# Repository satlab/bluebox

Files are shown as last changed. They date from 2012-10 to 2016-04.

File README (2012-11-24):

About the BlueBox
-----------------

The bluebox is a USB-powered ground station box design for the AAUSAT3 cubesat
satellite. The device firmware, control software and hardware is licensed under
the MIT license with the hope that it may be useful to other cubesat projects.

The device is built around the Analog Devices ADF7021 transceiver and controlled
by an Atmel ATMEGA32U4 microcontroller with hardware USB. The firmware makes use
of the open source LUFA USB stack and uses libusb and pyusb for communication
between the device and control program, bbctl.

How to install bbctl
--------------------

Go to software/bbctl and run:

    $ sudo python2 setup.py install

Note that you need gcc to compile the FEC extension module.

How to build and flash the firmware
-----------------------------------

In order to communicate with device without being root, copy 49-bluebox.rules
and 49-atmel.rules to your udev rules directory (usually /etc/udev/rules.d).

Now, compile and flash the software. The bbctl dfu step can be omitted if
you're flashing the device for the first time:

    $ cd bluebox/software/firmware
    $ make clean all 
    $ bbctl dfu
    $ make program

You need dfu-programmer to program the device. Install it from your package
manager or from http://dfu-programmer.sourceforge.net/

Finally, test the device by reading back the silicon revision of the ADF7021 RF
chip:

    $ bbctl version
    0x2104

You can run bbctl help to get a list of available commands.

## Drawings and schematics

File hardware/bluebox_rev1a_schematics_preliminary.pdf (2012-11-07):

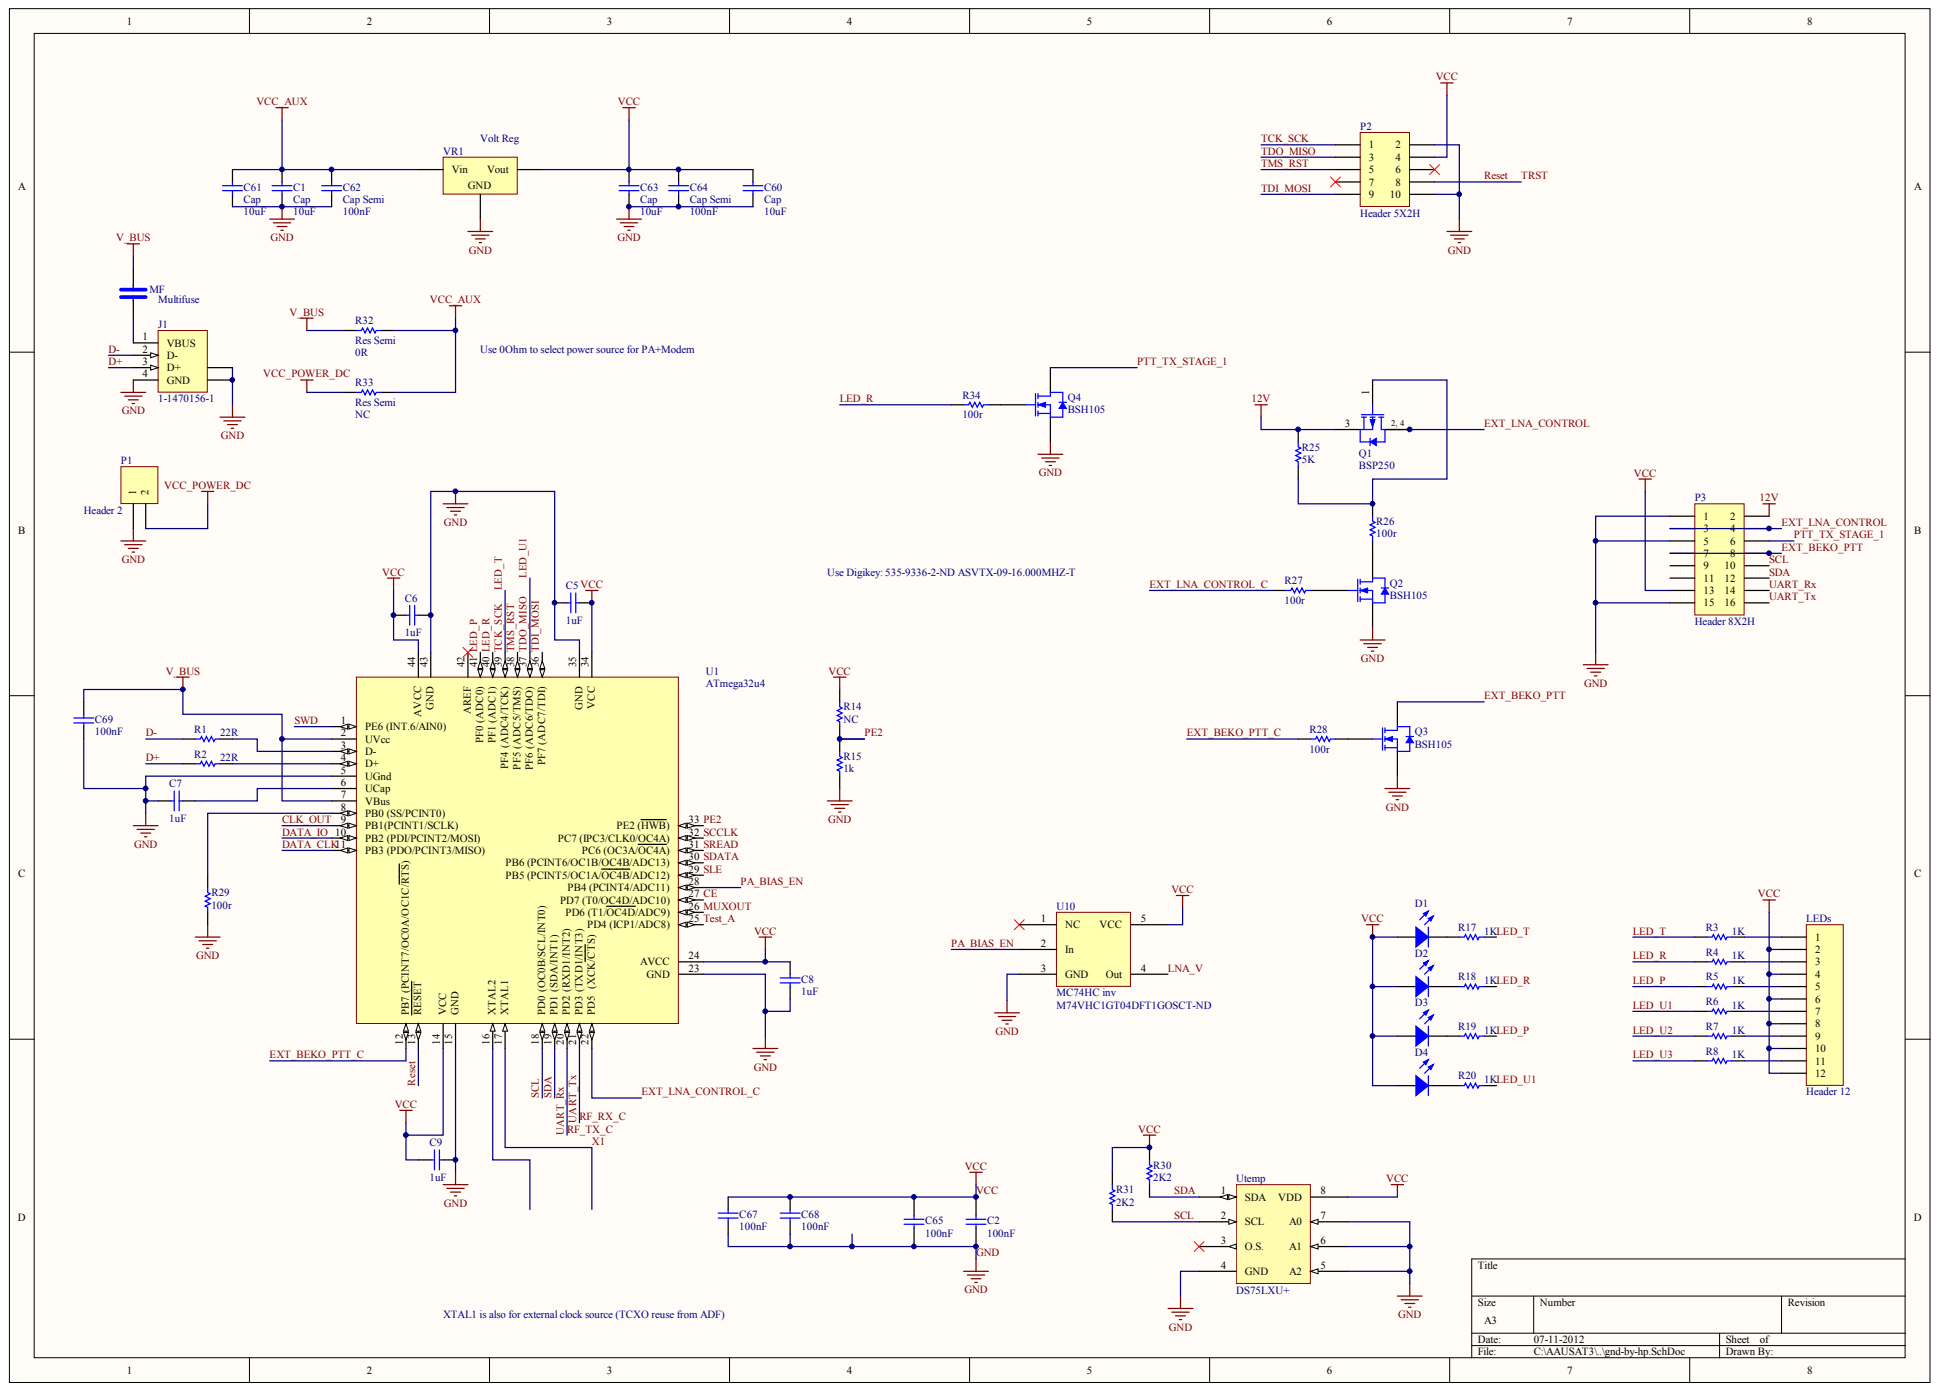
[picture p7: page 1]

Use 0Ohm to select power source for PA+Modem

5 6
7 8 9 10 11 12 13 14 15 16

Use Digikey: 535-9336-2-ND ASVTX-09-16.000MHZ-T

D+ 4 UGnd 5

UCap 6
VBus 7
PB0 (SS/PCINT0) 8

CLK_OUT | | PB1(PCINT1/SCLK) 9

XTAL1 is also for external clock source (TCXO reuse from ADF)

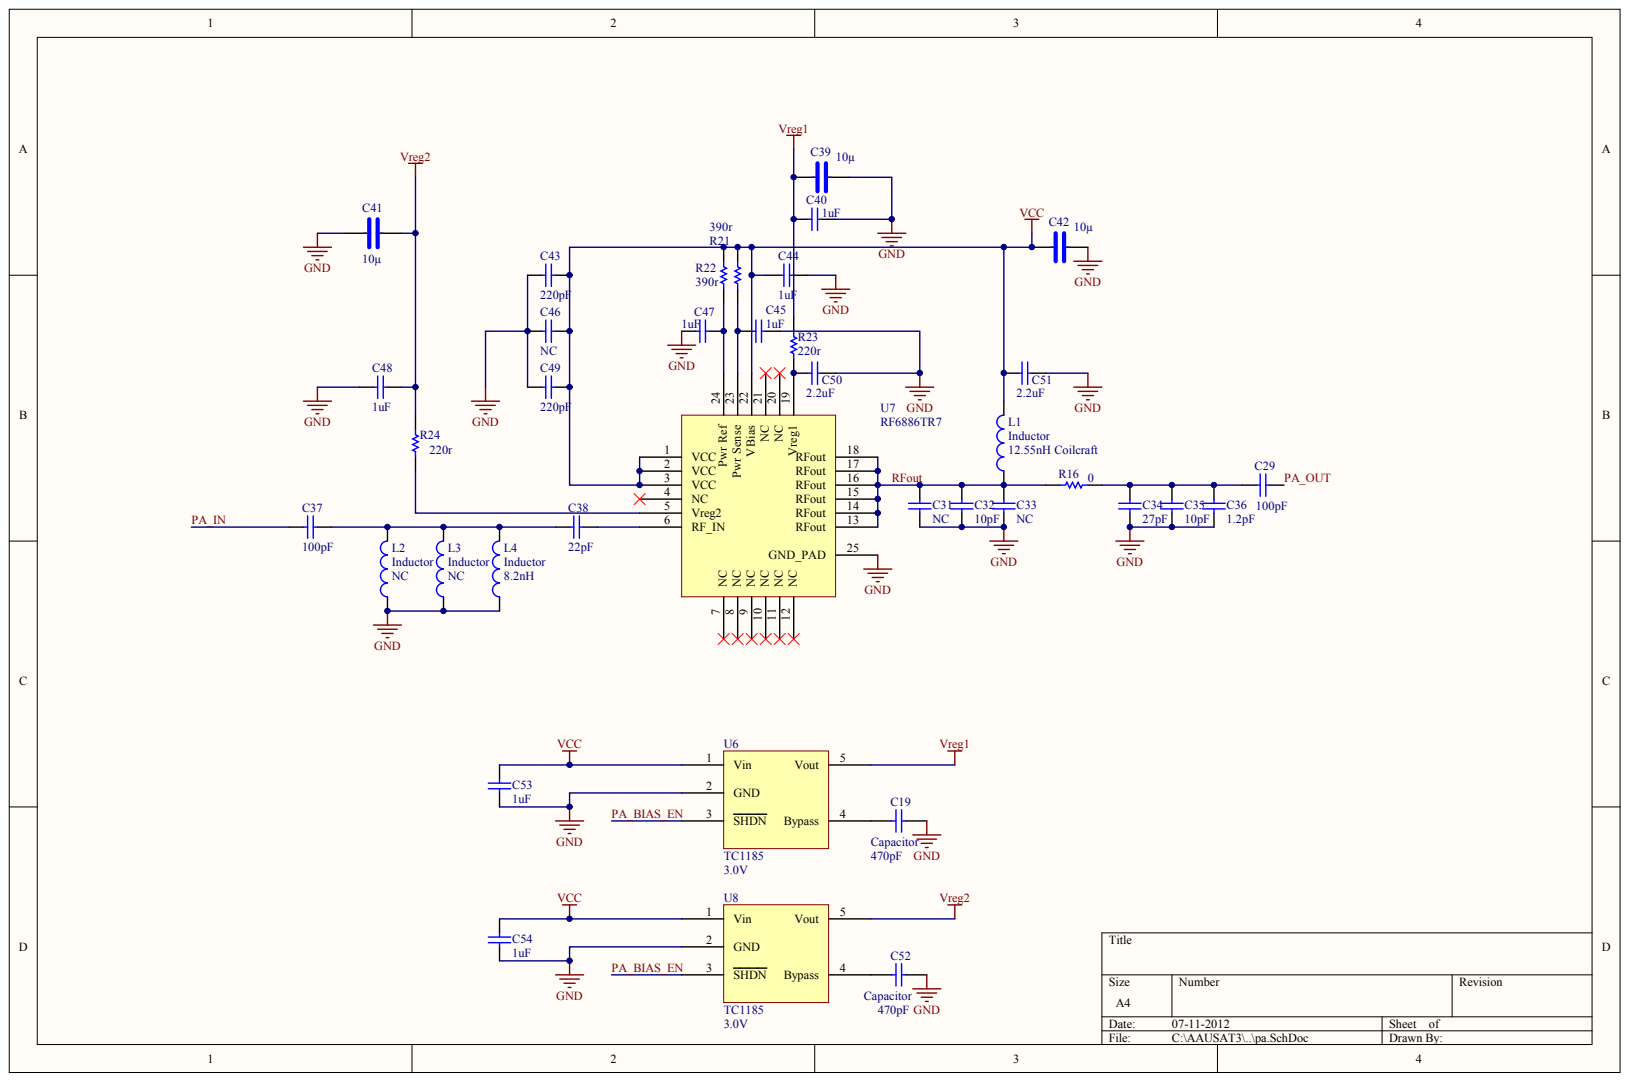
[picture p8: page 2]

18 reg1 19 NC 20 NC 21 VBias 22 Pwr Sense 23 Pwr Ref 24

NC 12 RFout 13 RFout 14 RFout 15 RFout 16 RFout 17 RFout V

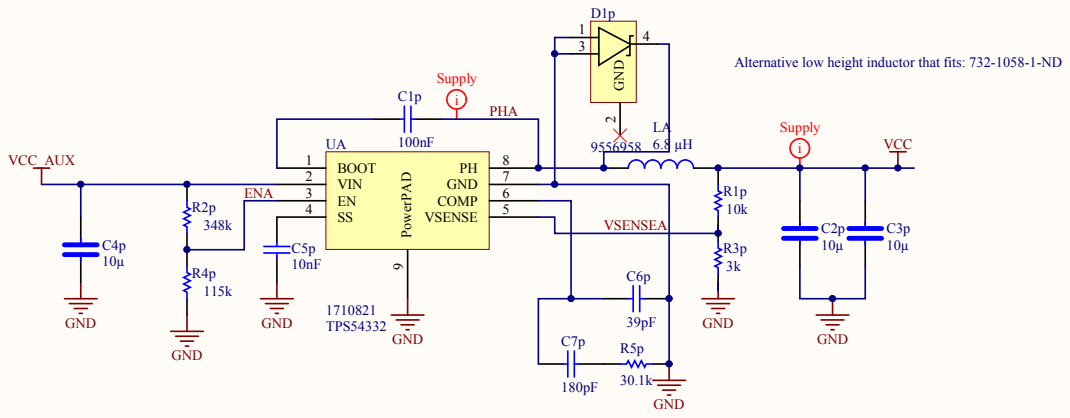
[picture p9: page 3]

Alternative low height inductor that fits: 732-1058-1-ND

ENA 3

V SENSEA

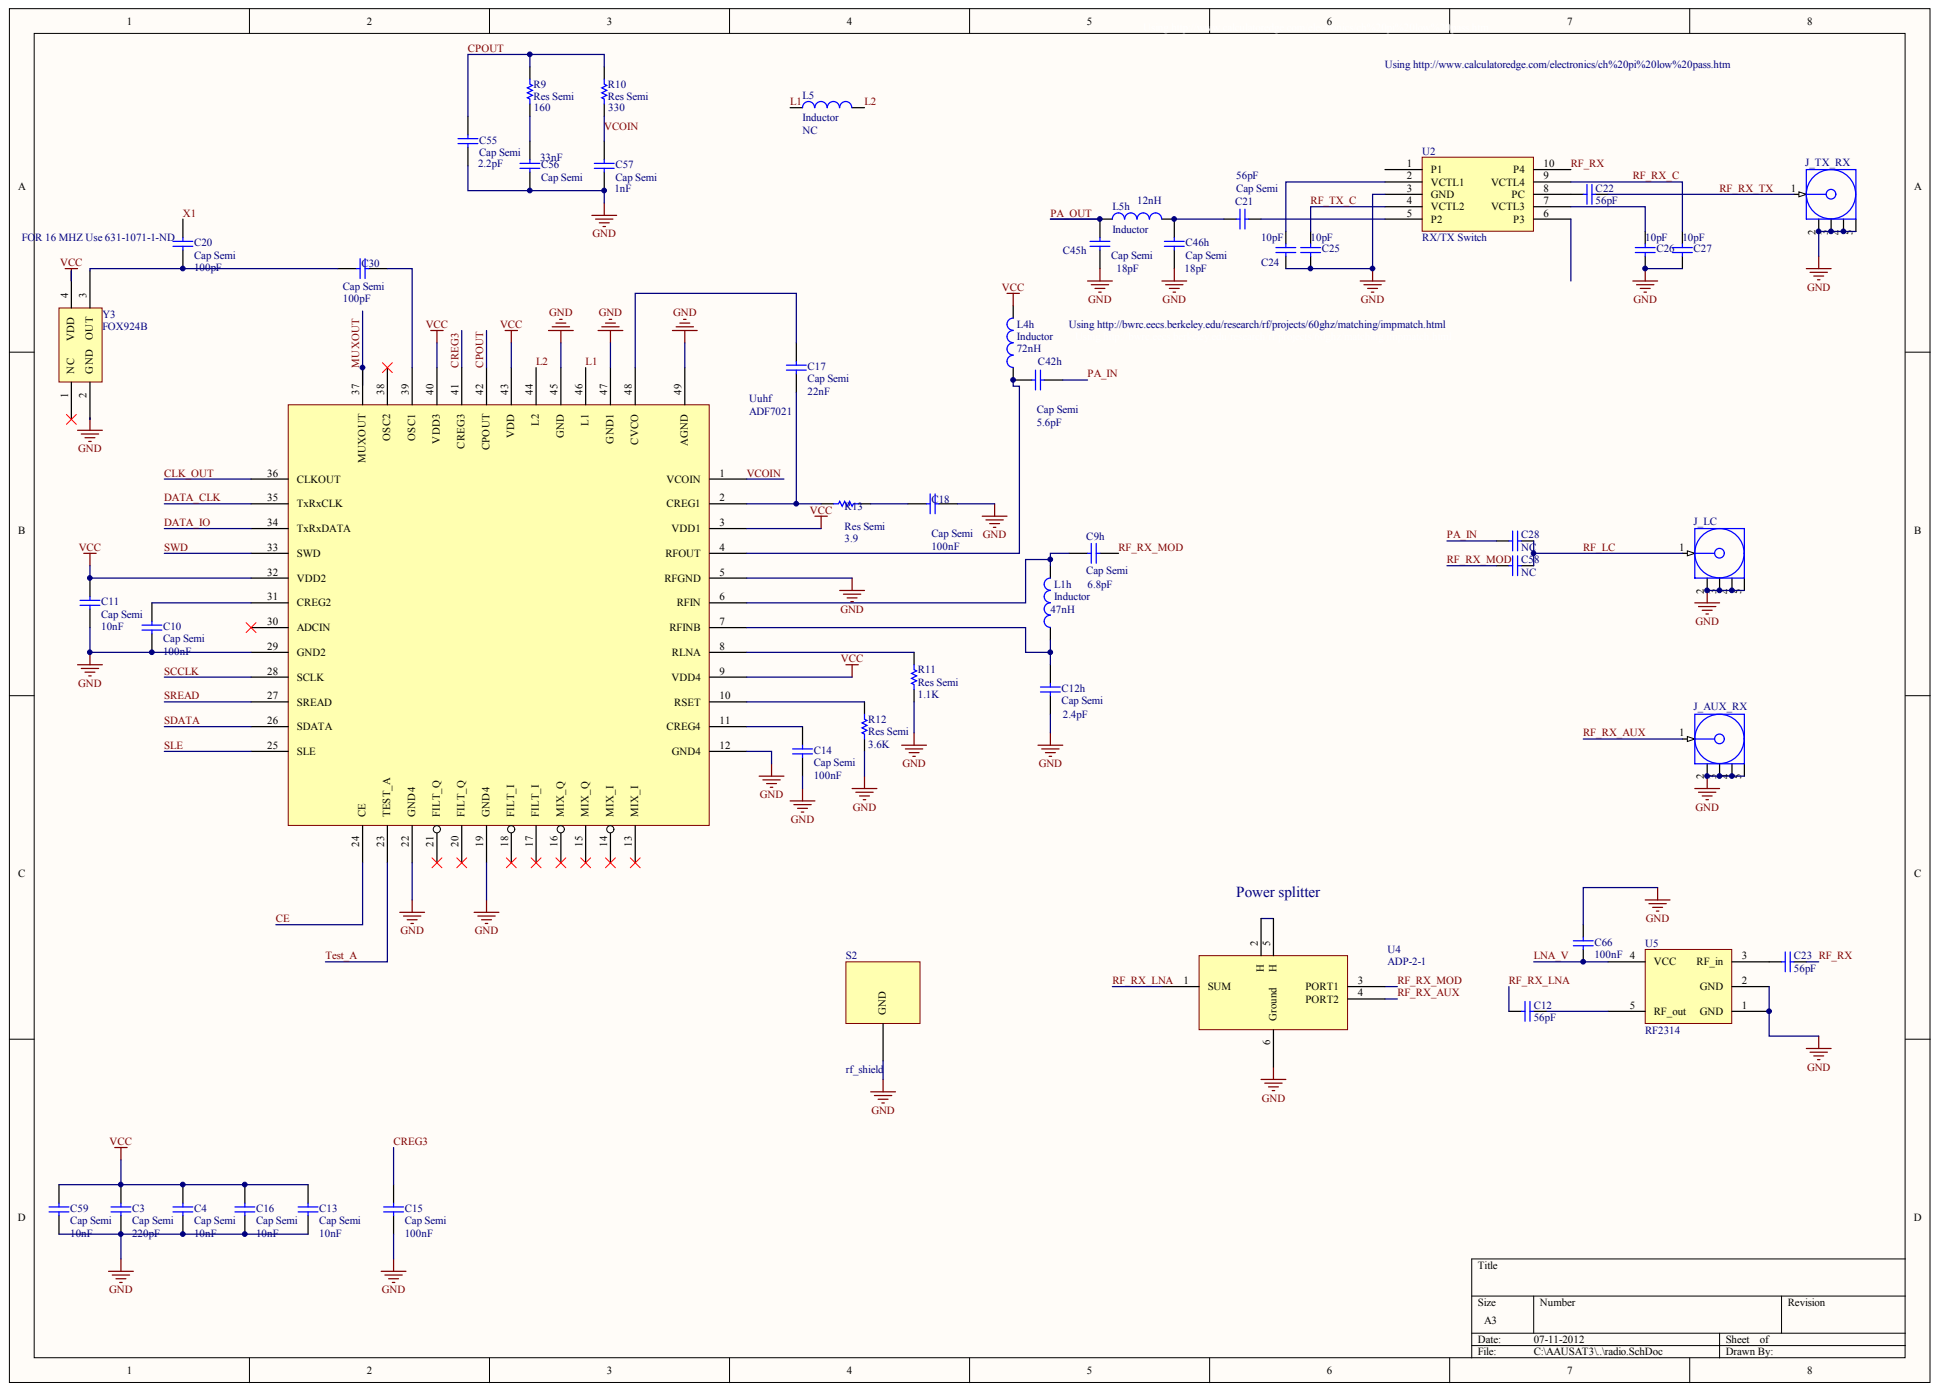
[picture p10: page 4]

Using http://www.calculatoredge.com/electronics/ch%20pi%20low%20pass.htm

FOR 16 MHZ Use 631-1071-1-ND

Using http://bwrc.eecs.berkeley.edu/research/rf/projects/60ghz/matching/impmatch.html

Cap Semi | | GND2 29

SCLK 28 SREAD 27 SDATA 26 SLE 25 | VCC

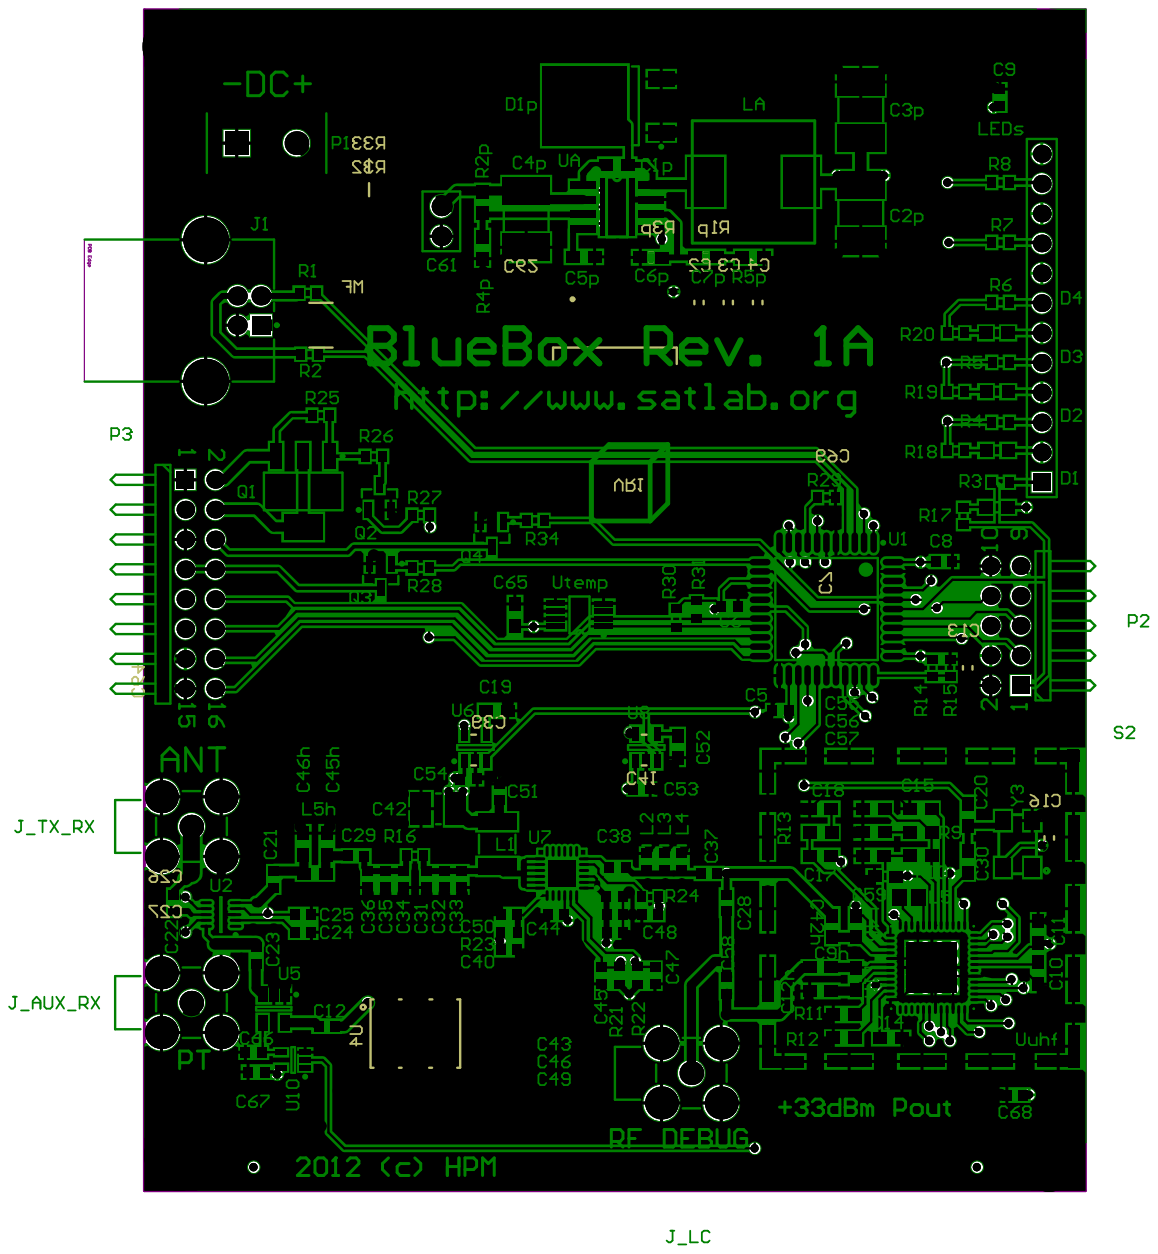
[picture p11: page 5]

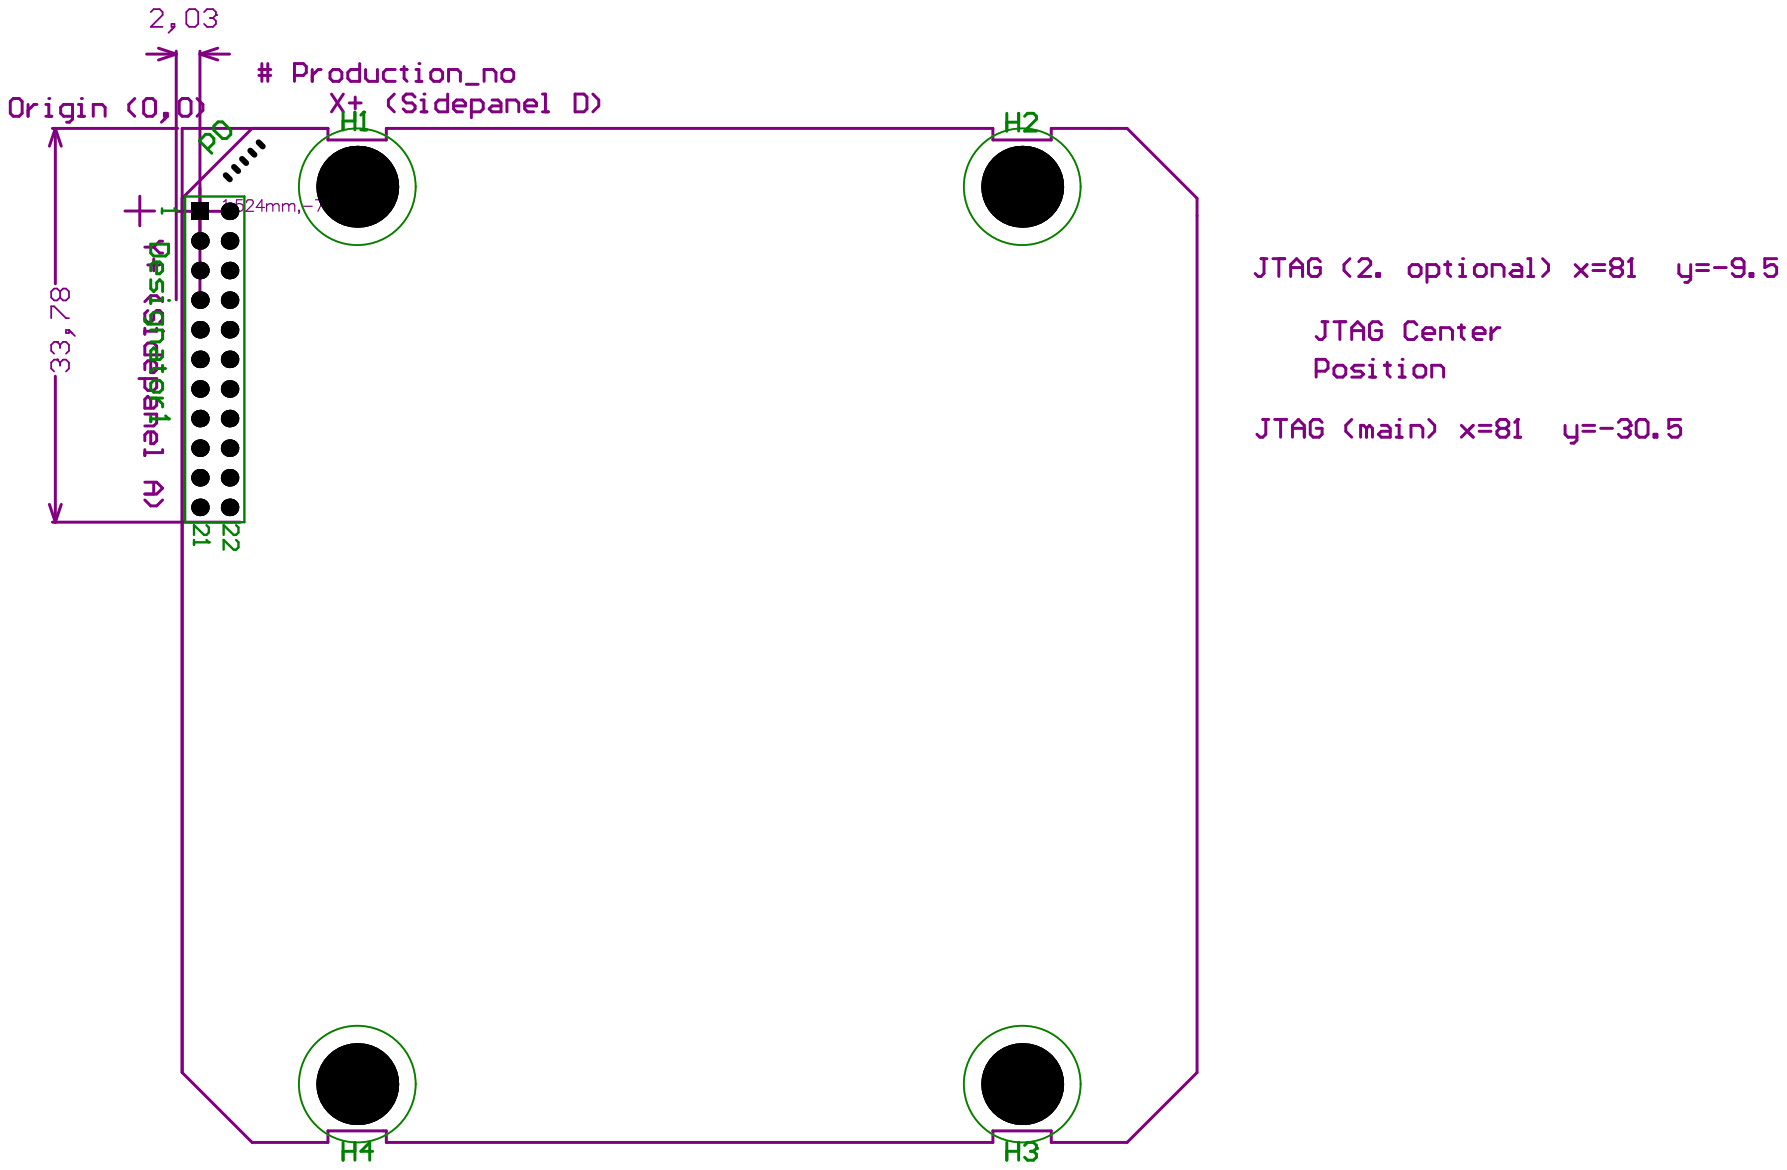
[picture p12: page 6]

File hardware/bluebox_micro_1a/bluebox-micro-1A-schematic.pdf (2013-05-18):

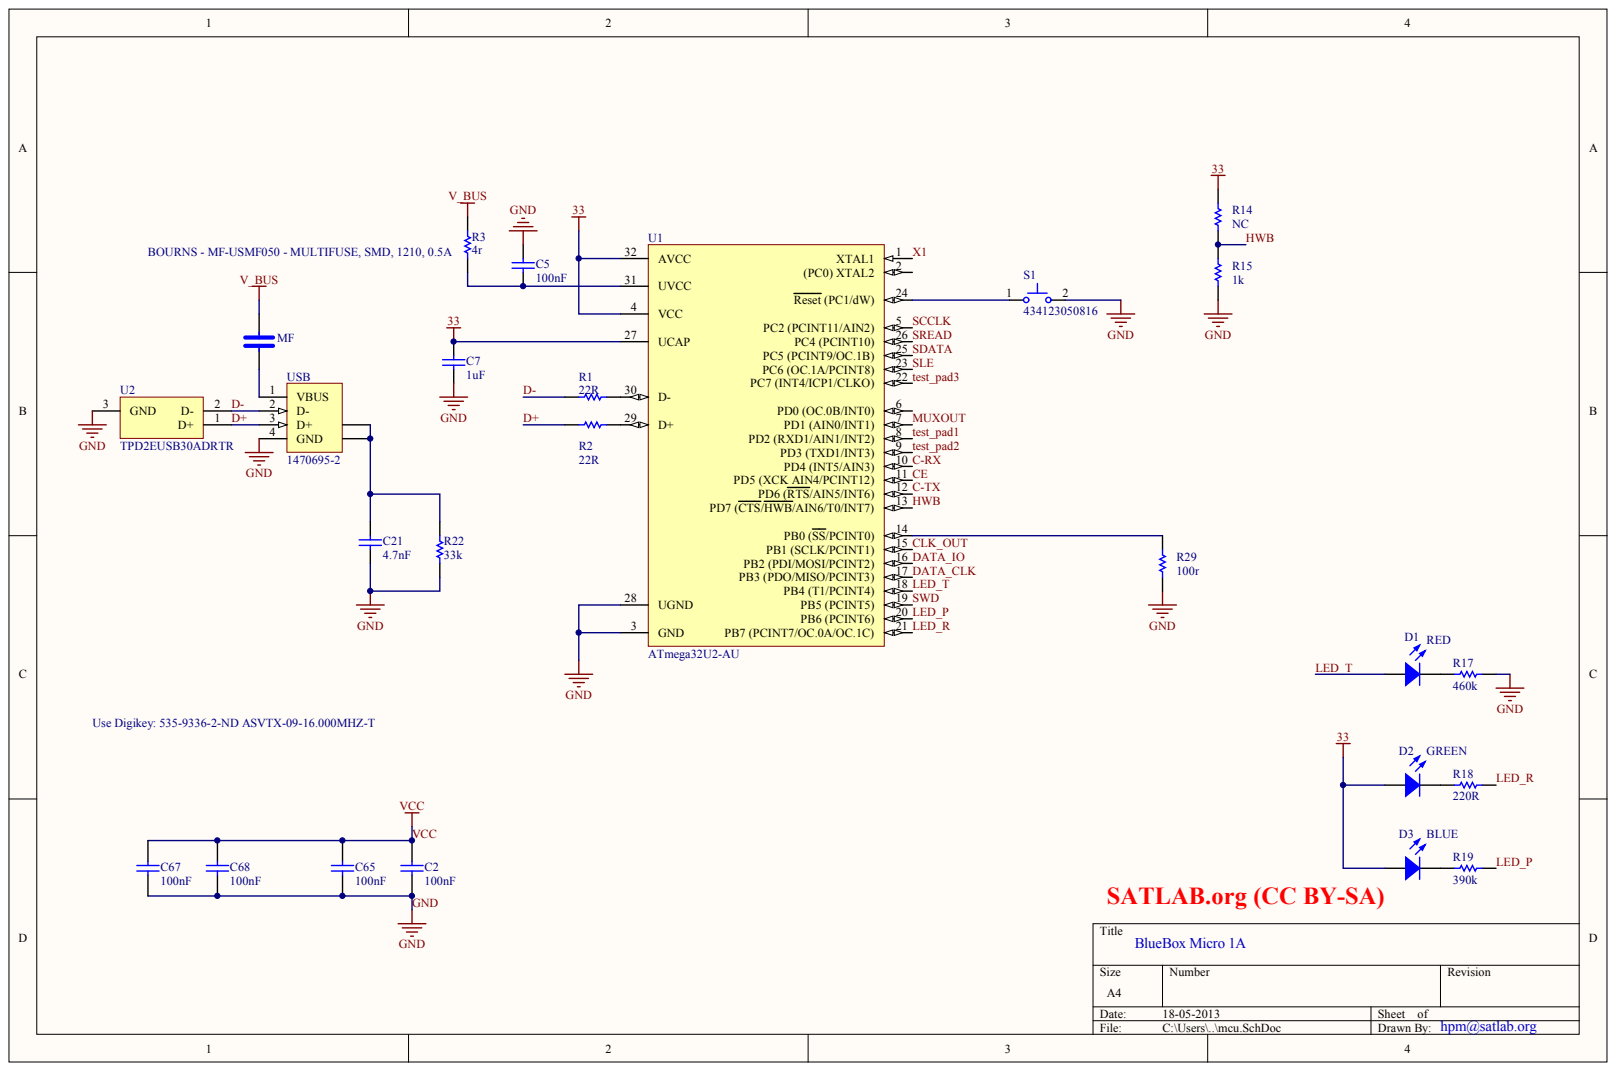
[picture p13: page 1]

SATLAB.org (CC BY-SA)

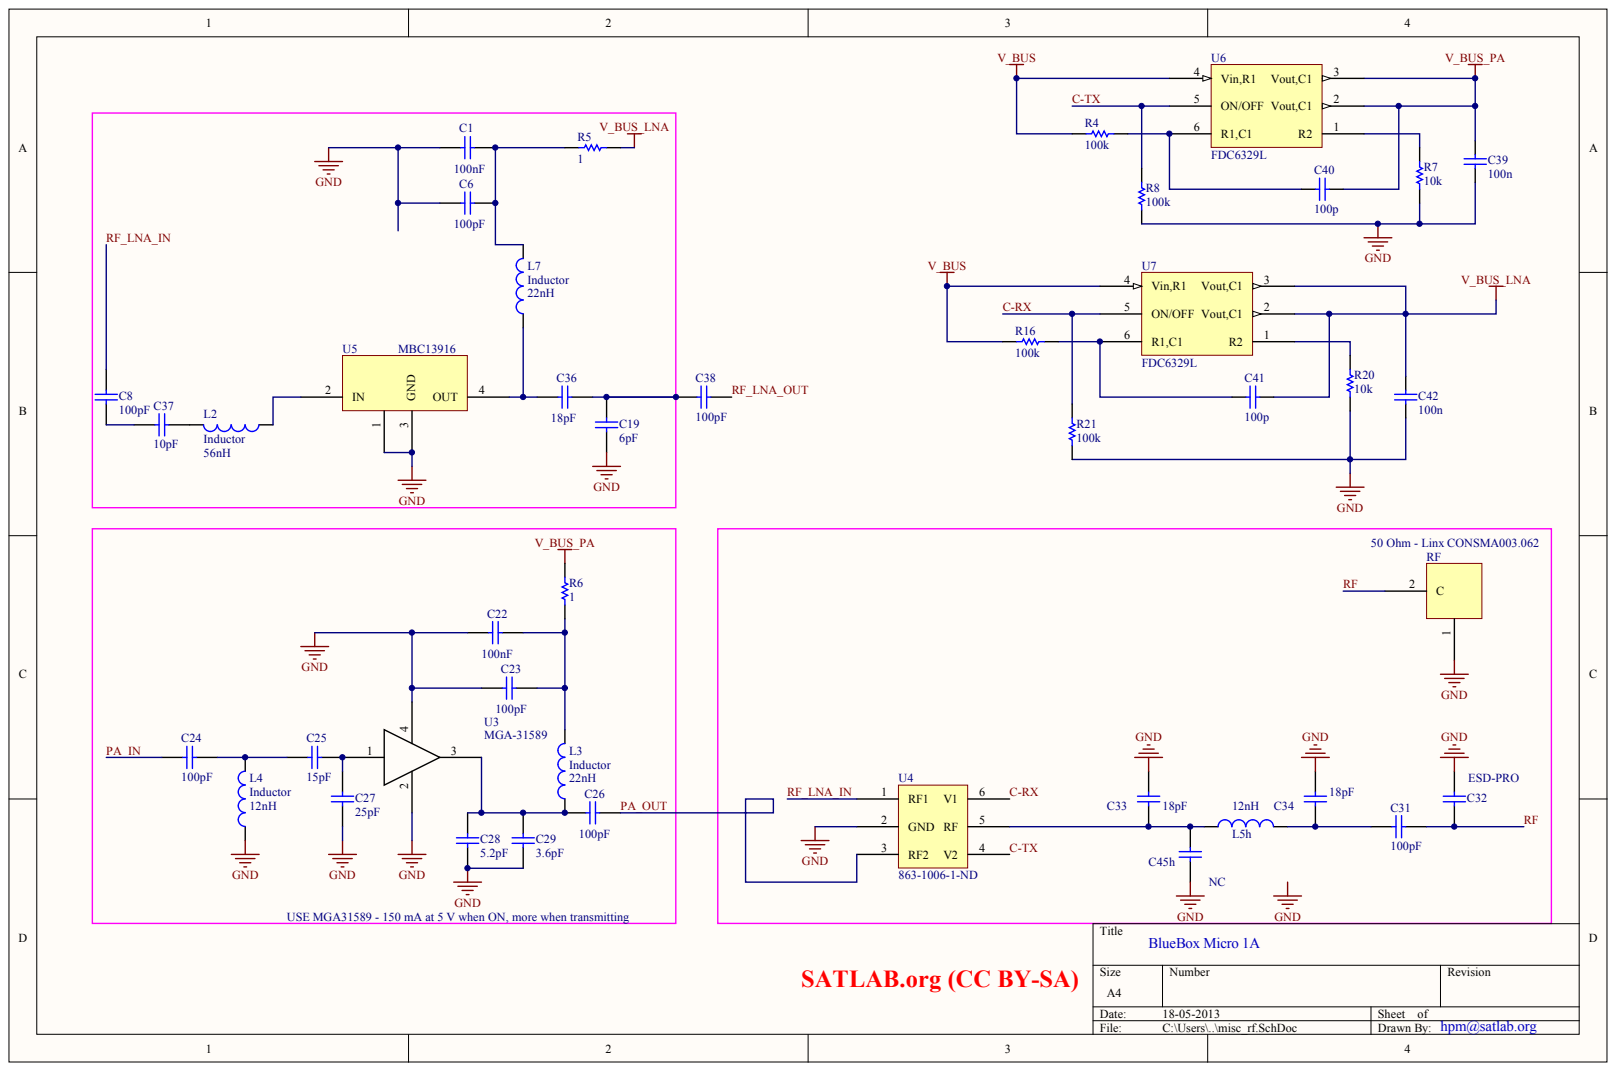
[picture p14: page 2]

C-TX | ON/OFF 5

C-RX | ON/OFF 5

USE MGA31589 - 150 mA at 5 V when ON, more when transmitting

SATLAB.org (CC BY-SA)

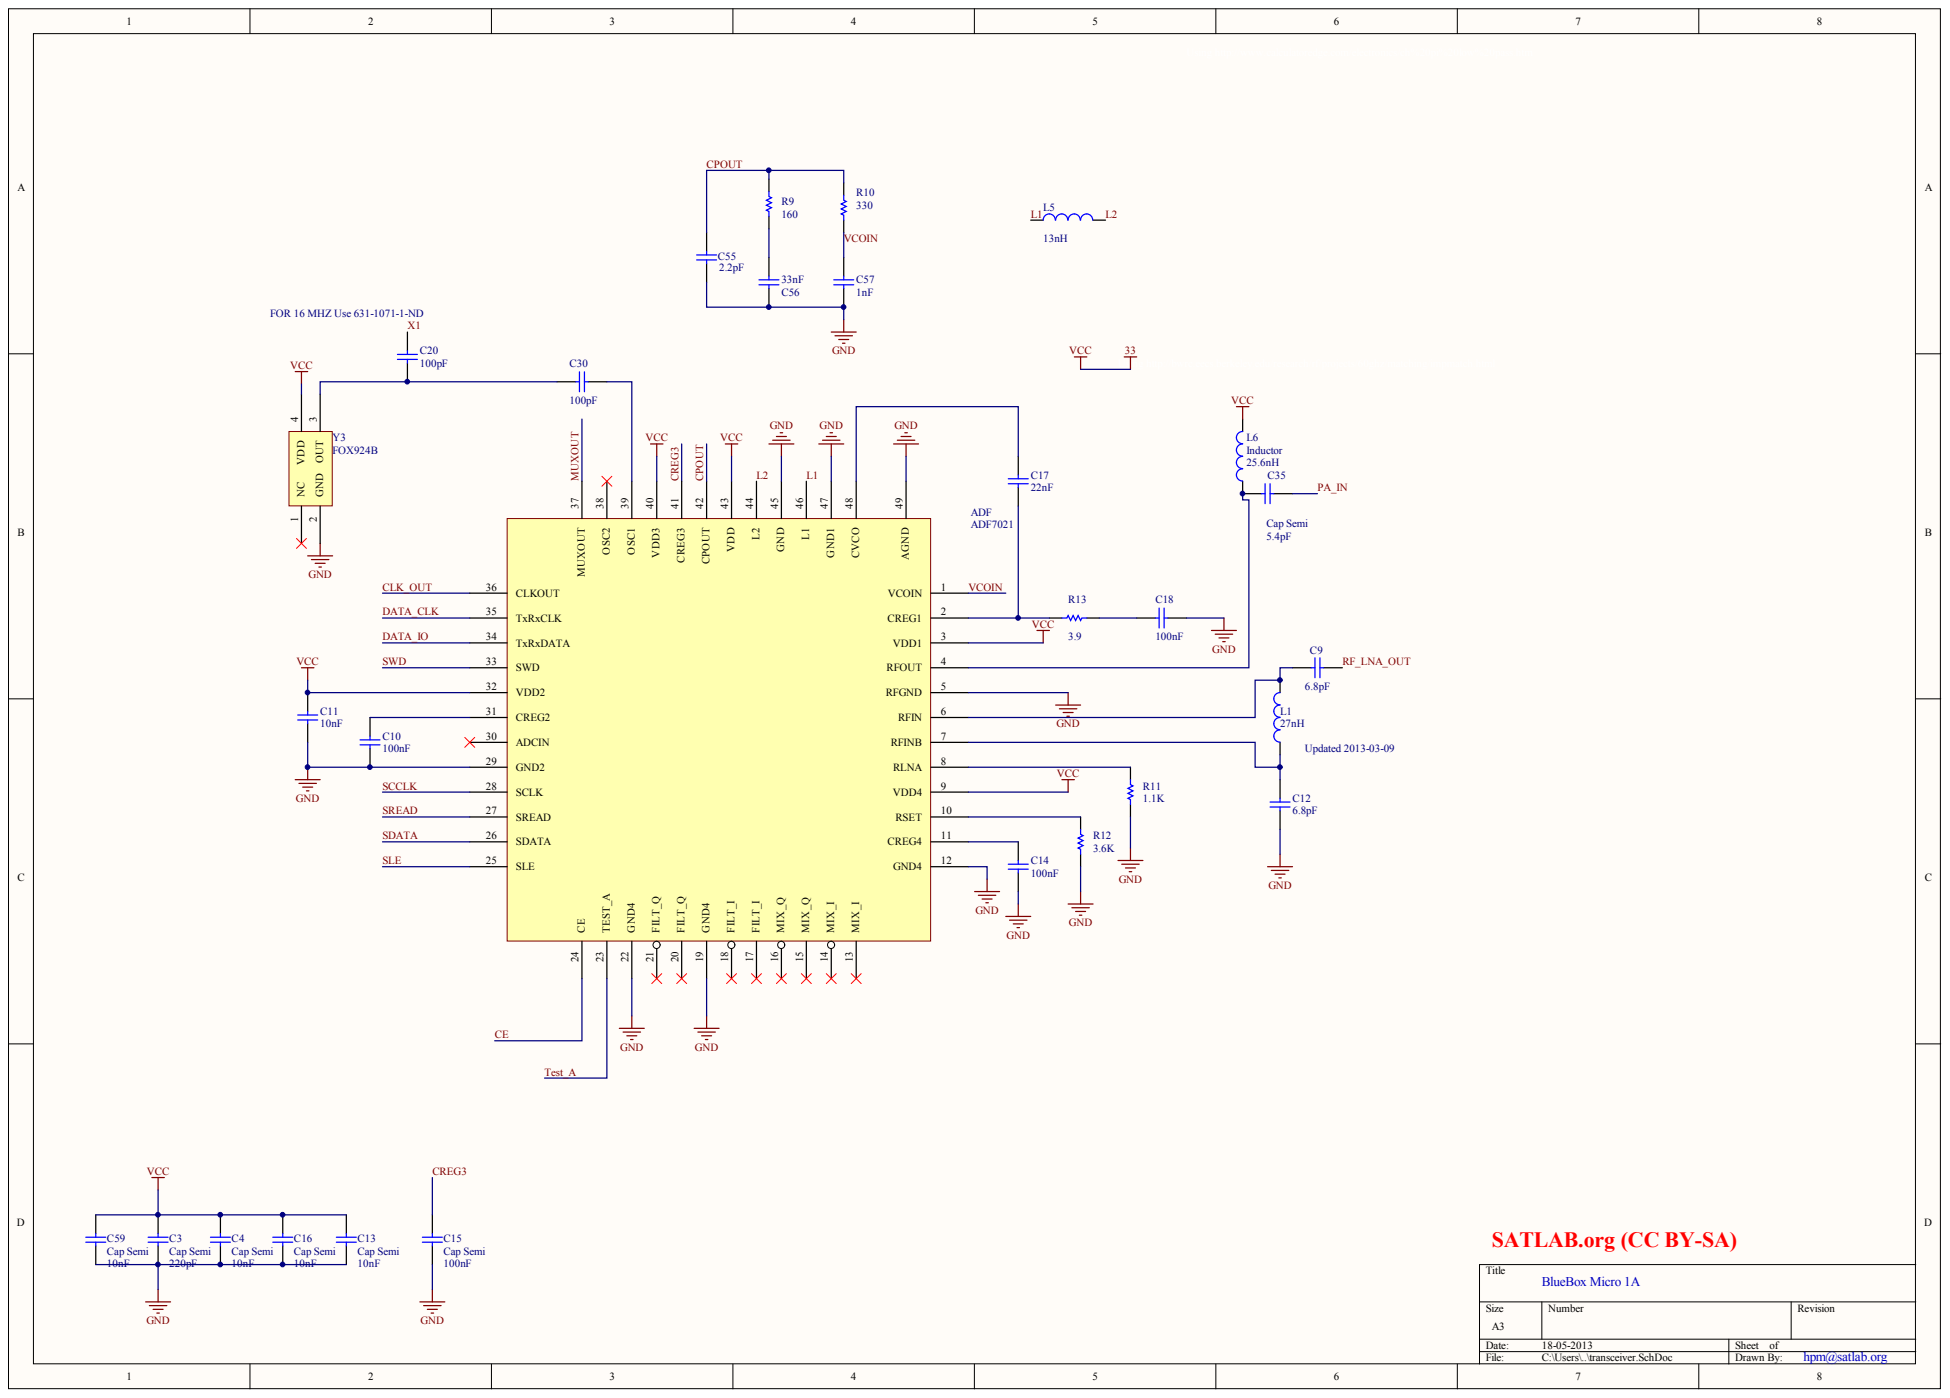
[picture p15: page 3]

Using http://www.calculatoredge.com/electronics/ch%20pi%20low%20pass.htm

FOR 16 MHZ Use 631-1071-1-ND

Using http://bwrc.eecs.berkeley.edu/research/rf/projects/60ghz/matching/impmatch.html

SATLAB.org (CC BY-SA)

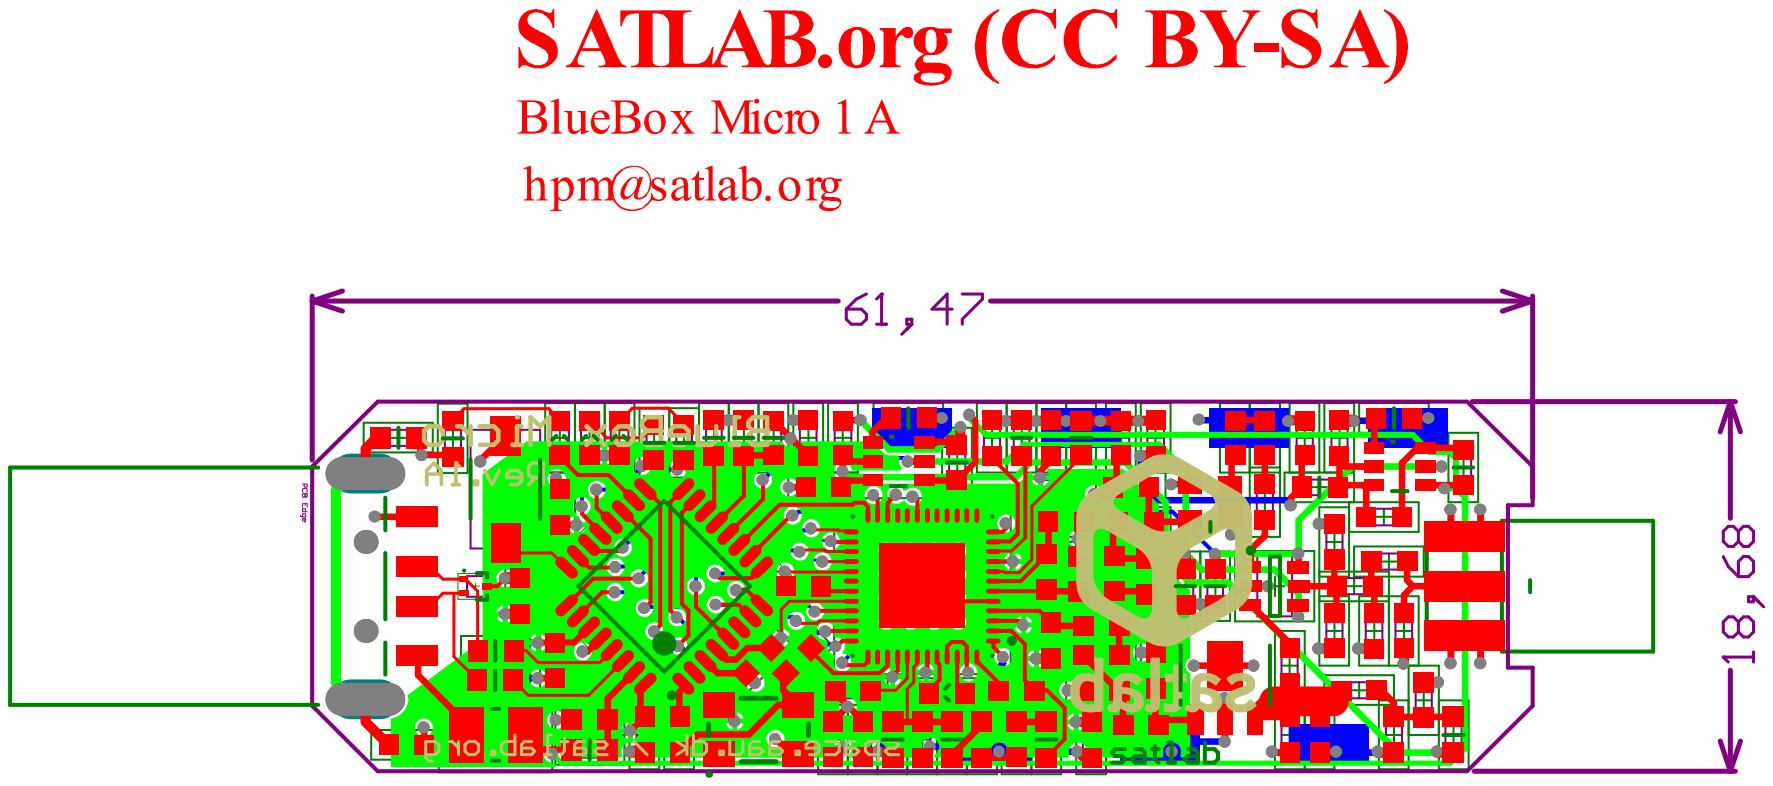
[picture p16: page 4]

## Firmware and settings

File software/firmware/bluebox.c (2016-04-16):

/*
 * Copyright (c) 2012 Jeppe Ledet-Pedersen <jlp@satlab.org>
 *
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
 * THE SOFTWARE IS PROVIDED "AS IS", WITHOUT WARRANTY OF ANY KIND, EXPRESS OR
 * IMPLIED, INCLUDING BUT NOT LIMITED TO THE WARRANTIES OF MERCHANTABILITY,
 * FITNESS FOR A PARTICULAR PURPOSE AND NONINFRINGEMENT. IN NO EVENT SHALL THE
 * AUTHORS OR COPYRIGHT HOLDERS BE LIABLE FOR ANY CLAIM, DAMAGES OR OTHER
 * LIABILITY, WHETHER IN AN ACTION OF CONTRACT, TORT OR OTHERWISE, ARISING FROM,
 * OUT OF OR IN CONNECTION WITH THE SOFTWARE OR THE USE OR OTHER DEALINGS IN
 * THE SOFTWARE.
 */

#include <stdint.h>
#include <stdbool.h>
#include <errno.h>

#include "bluebox.h"
#include "adf7021.h"
#include "bootloader.h"
#include "spi.h"
#include "led.h"
#include "ptt.h"

#define rf_config_single(_type, _name) 						\
	_type _name; 								\
	if (direction == ENDPOINT_DIR_OUT) {					\
		Endpoint_Read_Control_Stream_LE(&_name, sizeof(_name));		\
		conf._name = _name;						\
		conf_set_reconf();						\
	} else if (direction == ENDPOINT_DIR_IN) {				\
		Endpoint_Write_Control_Stream_LE(&conf._name, sizeof(conf._name)); \
	}

struct bluebox_config conf = {
	.flags = CONF_FLAG_NONE,
	.tx_freq = FREQUENCY,
	.rx_freq = FREQUENCY,
	.csma_rssi = CSMA_RSSI,
	.bitrate = BAUD_RATE,
	.modindex = MOD_INDEX,
	.pa_setting = PA_SETTING,
	.afc_range = AFC_RANGE,
	.afc_ki = AFC_KI,
	.afc_kp = AFC_KP,
	.afc_enable = AFC_ENABLE,
	.if_bw = IF_FILTER_BW,
	.sw = SYNC_WORD,
	.swtol = SYNC_WORD_TOLERANCE,	
	.swlen = SYNC_WORD_BITS,
	.do_rs = true,
	.do_viterbi = true,
	.callsign = CALLSIGN,
	.training_ms = TRAINING_MS,
	.training_inter_ms = TRAINING_INTER_MS,
	.training_symbol = TRAINING_SYMBOL,
	.ptt_delay_high = PTT_DELAY_HIGH,
	.ptt_delay_low = PTT_DELAY_LOW,
	.tx = 0,
	.rx = 0,
	.fw_revision = FW_REVISION,
};

static inline bool conf_should_reconf(void)
{
	return (conf.flags & CONF_FLAG_RECONFIGURE);
}

static inline void conf_set_reconf(void)
{
	conf.flags |= CONF_FLAG_RECONFIGURE;
}

static inline void conf_clear_reconf(void)
{
	conf.flags &= ~CONF_FLAG_RECONFIGURE;
}

uint32_t serialno __attribute__((section(".eeprom")));

static void setup_hardware(void)
{
	MCUSR &= ~(1 << WDRF);
	wdt_disable();

	clock_prescale_set(clock_div_1);

	ptt_init();
	USB_Init();
	led_init();

	/* Initialize SPI */
	spi_init_config(SPI_SLAVE | SPI_MSB_FIRST);
}

static void callsign_init(char *cs)
{
	int i;

	for (i = 0; i < CALLSIGN_LENGTH; i++) {
		conf.callsign[i] = cs[i];
		if (i < SYNC_WORD_LENGTH)
			conf.sw |= (uint32_t)conf.callsign[i] << 8 * (SYNC_WORD_LENGTH - i - 1);
	}
}

static void do_register(int direction, unsigned int regnum)
{
	uint32_t value;
	adf_reg_t reg;

	if (direction == ENDPOINT_DIR_OUT) {
		Endpoint_Read_Control_Stream_LE(&value, sizeof(value));
		value = (value & ~0xf) | (regnum & 0xf);
		reg.whole_reg = value;
		adf_write_reg(&reg);
	} else if (direction == ENDPOINT_DIR_IN) {
		reg = adf_read_reg(regnum);
		value = reg.whole_reg;
		Endpoint_Write_Control_Stream_LE(&value, sizeof(value));
	}
}

static void do_rxtx_mode(int direction, unsigned int wValue)
{
	if (wValue != 0)
		adf_set_tx_mode();
	else
		adf_set_rx_mode();
}

static void do_tx_frequency(int direction, unsigned int vWalue)
{
	rf_config_single(uint32_t, tx_freq);
}

static void do_rx_frequency(int direction, unsigned int vWalue)
{
	rf_config_single(uint32_t, rx_freq);
}

static void do_frequency(int direction, unsigned int wValue)
{
	uint32_t freq;

	if (direction == ENDPOINT_DIR_OUT) {
		Endpoint_Read_Control_Stream_LE(&freq, sizeof(freq));
		conf.tx_freq = freq;
		conf.rx_freq = freq;
		conf_set_reconf();
	} else if (direction == ENDPOINT_DIR_IN) {
		Endpoint_Write_Control_Stream_LE(&conf.rx_freq, sizeof(conf.rx_freq)); \
	}
}

static void do_modindex(int direction, unsigned int vWalue)
{
	rf_config_single(uint8_t, modindex);
}

static void do_csma_rssi(int direction, unsigned int vWalue)
{
	rf_config_single(int16_t, csma_rssi);
}

static void do_power(int direction, unsigned int vWalue)
{
	rf_config_single(uint8_t, pa_setting);
}

struct afc_request {
	uint8_t state;
	uint8_t range;
	uint8_t p;
	uint8_t i;
} __attribute__ ((packed));
	
static void do_acf(int direction, unsigned int vWalue)
{
	struct afc_request req;

	if (direction == ENDPOINT_DIR_OUT) {
		Endpoint_Read_Control_Stream_LE(&req, sizeof(req));
		conf.afc_enable = !!req.state;
		conf.afc_range = req.range ? req.range : conf.afc_range;
		conf.afc_kp = req.p ? req.p : conf.afc_kp;
		conf.afc_ki = req.i ? req.i : conf.afc_ki;
		conf_set_reconf();
	} else if (direction == ENDPOINT_DIR_IN) {
		req.state = conf.afc_enable;
		req.range = conf.afc_range;
		req.p = conf.afc_kp;
		req.i = conf.afc_ki;
		Endpoint_Write_Control_Stream_LE(&req, sizeof(req));
	}
}

static void do_ifbw(int direction, unsigned int vWalue)
{
	rf_config_single(uint8_t, if_bw);
}

static void do_training(int direction, unsigned int vWalue)
{
	rf_config_single(uint16_t, training_ms);
}

static void do_syncword(int direction, unsigned int vWalue)
{
	rf_config_single(uint32_t, sw);
}

static void do_bitrate(int direction, unsigned int vWalue)
{
	rf_config_single(uint16_t, bitrate);
}

static void do_tx(int direction, unsigned int vWalue)
{
	rf_config_single(uint32_t, tx);
}

static void do_rx(int direction, unsigned int vWalue)
{
	rf_config_single(uint32_t, rx);
}

static void do_fw_revision(int direction, unsigned int vWalue)
{
	char fwrev[9];

	if (direction == ENDPOINT_DIR_IN) {
		memset(fwrev, ' ', 9);
		snprintf(fwrev, 9, "%s", conf.fw_revision);
		fwrev[8] = '\0';
		Endpoint_Write_Control_Stream_LE(fwrev, 8);
	}
}

static void do_serialnumber(int direction, unsigned int vWalue)
{
	uint32_t snum;

	if (direction == ENDPOINT_DIR_OUT) {
		Endpoint_Read_Control_Stream_LE(&snum, sizeof(snum));
		eeprom_write_dword(&serialno, snum);
	} else if (direction == ENDPOINT_DIR_IN) {
		snum = eeprom_read_dword(&serialno);
		Endpoint_Write_Control_Stream_LE(&snum, sizeof(snum));
	}
}

static void do_control_request(int direction)
{
	switch (USB_ControlRequest.bRequest) {
	case REQUEST_REGISTER:
		do_register(direction, USB_ControlRequest.wValue);
		break;
	case REQUEST_FREQUENCY:
		do_frequency(direction, USB_ControlRequest.wValue);
		break;
	case REQUEST_RXTX_MODE:
		do_rxtx_mode(direction, USB_ControlRequest.wValue);
		break;
	case REQUEST_MODINDEX:
		do_modindex(direction, USB_ControlRequest.wValue);
		break;
	case REQUEST_CSMA_RSSI:
		do_csma_rssi(direction, USB_ControlRequest.wValue);
		break;
	case REQUEST_POWER:
		do_power(direction, USB_ControlRequest.wValue);
		break;
	case REQUEST_AFC:
		do_acf(direction, USB_ControlRequest.wValue);
		break;
	case REQUEST_IFBW:
		do_ifbw(direction, USB_ControlRequest.wValue);
		break;
	case REQUEST_TRAINING:	
		do_training(direction, USB_ControlRequest.wValue);
		break;
	case REQUEST_SYNCWORD:	
		do_syncword(direction, USB_ControlRequest.wValue);
		break;
	case REQUEST_BITRATE:
		do_bitrate(direction, USB_ControlRequest.wValue);
		break;
	case REQUEST_TX:
		do_tx(direction, USB_ControlRequest.wValue);
		break;
	case REQUEST_RX:
		do_rx(direction, USB_ControlRequest.wValue);
		break;
	case REQUEST_TX_FREQUENCY:
		do_tx_frequency(direction, USB_ControlRequest.wValue);
		break;
	case REQUEST_RX_FREQUENCY:
		do_rx_frequency(direction, USB_ControlRequest.wValue);
		break;
	case REQUEST_SERIALNUMBER:
		do_serialnumber(direction, USB_ControlRequest.wValue);
		break;
	case REQUEST_FWREVISION:
		do_fw_revision(direction, USB_ControlRequest.wValue);
		break;
	case REQUEST_RESET:
		reboot();
		break;
	case REQUEST_DFU:
		jump_to_bootloader();
		break;
	}
}

static bool csma_tx_allowed(void)
{
	int rssi;
	static unsigned int quarantine = 0;

	if (quarantine > 0) {
		quarantine--;
		delay_ms(1);
	}

	rssi = adf_readback_rssi();

	if (rssi > conf.csma_rssi)
		quarantine = 100;

	return (rssi <= conf.csma_rssi);
}

static void tx_task(void)
{
	if (USB_DeviceState != DEVICE_STATE_Configured)
		return;

	Endpoint_SelectEndpoint(OUT_EPADDR);
	if (Endpoint_IsOUTReceived() && csma_tx_allowed() && spi_tx_prepare()) {
		if (Endpoint_IsReadWriteAllowed()) {
			if (!(data[front].flags & FLAG_TX_READY)) {
				Endpoint_Read_Stream_LE(&data[front], sizeof(data[front]), NULL);
				data[front].flags |= FLAG_TX_READY;
				adf_set_tx_mode();
				spi_tx_start();
			} else {
				Endpoint_Read_Stream_LE(&data[back], sizeof(data[back]), NULL);
				data[back].flags |= FLAG_TX_READY;
			}
			Endpoint_ClearOUT();
		}
	}
}

static void conf_task(void)
{
	cli();

	if (!spi_busy() && conf_should_reconf()) {
		adf_configure();
		conf_clear_reconf();
	}

	sei();
}

void EVENT_USB_Device_ControlRequest(void)
{
	switch (USB_ControlRequest.bmRequestType) {
	case (REQDIR_HOSTTODEVICE | REQTYPE_CLASS | REQREC_INTERFACE):
		Endpoint_ClearSETUP();
		do_control_request(ENDPOINT_DIR_OUT);
		Endpoint_ClearIN();
		break;
	case (REQDIR_DEVICETOHOST | REQTYPE_CLASS | REQREC_INTERFACE):
		Endpoint_ClearSETUP();
		do_control_request(ENDPOINT_DIR_IN);
		Endpoint_ClearOUT();
		break;
	default:
		break;
	}
}

int main(void)
{
	setup_hardware();
	GlobalInterruptEnable();

	callsign_init(conf.callsign);

	led_off(LED_ALL);

	adf_set_power_on(XTAL_FREQ);
	adf_configure();
	adf_set_rx_mode();

	swd_init();
	swd_enable();

	led_on(LED_POWER);

	while (1) {
		conf_task();
		rx_task();
		tx_task();
		USB_USBTask();
	}
}

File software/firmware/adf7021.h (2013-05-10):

/*
 * Copyright (c) 2008 Johan Christiansen
 * Copyright (c) 2012 Jeppe Ledet-Pedersen <jlp@satlab.org>
 *
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
 * THE SOFTWARE IS PROVIDED "AS IS", WITHOUT WARRANTY OF ANY KIND, EXPRESS OR
 * IMPLIED, INCLUDING BUT NOT LIMITED TO THE WARRANTIES OF MERCHANTABILITY,
 * FITNESS FOR A PARTICULAR PURPOSE AND NONINFRINGEMENT. IN NO EVENT SHALL THE
 * AUTHORS OR COPYRIGHT HOLDERS BE LIABLE FOR ANY CLAIM, DAMAGES OR OTHER
 * LIABILITY, WHETHER IN AN ACTION OF CONTRACT, TORT OR OTHERWISE, ARISING FROM,
 * OUT OF OR IN CONNECTION WITH THE SOFTWARE OR THE USE OR OTHER DEALINGS IN
 * THE SOFTWARE.
 */

#ifndef _ADF7021_H_
#define _ADF7021_H_

#include <stdint.h>
#include <stdbool.h>

#if defined(BBSTANDARD)
#define ADF_PORT_SWD		PORTE
#define ADF_PORT_IN_SWD		PINE
#define ADF_PORT_DIR_SWD	DDRE
#define ADF_SWD 		6

#define ADF_PORT_SCLK		PORTC
#define ADF_PORT_IN_SCLK	PINC
#define ADF_PORT_DIR_SCLK	DDRC
#define ADF_SCLK 		7

#define ADF_PORT_SREAD		PORTC
#define ADF_PORT_IN_SREAD	PINC
#define ADF_PORT_DIR_SREAD	DDRC
#define ADF_SREAD 		6

#define ADF_PORT_SDATA		PORTB
#define ADF_PORT_IN_SDATA	PINB
#define ADF_PORT_DIR_SDATA	DDRB
#define ADF_SDATA 		6

#define ADF_PORT_SLE		PORTB
#define ADF_PORT_IN_SLE		PINB
#define ADF_PORT_DIR_SLE	DDRB
#define ADF_SLE 		5

#define ADF_PORT_MUXOUT		PORTD
#define ADF_PORT_IN_MUXOUT	PIND
#define ADF_PORT_DIR_MUXOUT	DDRD
#define ADF_MUXOUT 		6

#define ADF_PORT_CE		PORTD
#define ADF_PORT_IN_CE		PIND
#define ADF_PORT_DIR_CE		DDRD
#define ADF_CE 			7
#elif defined(BBMICRO)
#define ADF_PORT_SWD		PORTB
#define ADF_PORT_IN_SWD		PINB
#define ADF_PORT_DIR_SWD	DDRB
#define ADF_SWD 		5

#define ADF_PORT_SCLK		PORTC
#define ADF_PORT_IN_SCLK	PINC
#define ADF_PORT_DIR_SCLK	DDRC
#define ADF_SCLK 		2

#define ADF_PORT_SREAD		PORTC
#define ADF_PORT_IN_SREAD	PINC
#define ADF_PORT_DIR_SREAD	DDRC
#define ADF_SREAD 		4

#define ADF_PORT_SDATA		PORTC
#define ADF_PORT_IN_SDATA	PINC
#define ADF_PORT_DIR_SDATA	DDRC
#define ADF_SDATA 		5

#define ADF_PORT_SLE		PORTC
#define ADF_PORT_IN_SLE		PINC
#define ADF_PORT_DIR_SLE	DDRC
#define ADF_SLE 		6

#define ADF_PORT_MUXOUT		PORTD
#define ADF_PORT_IN_MUXOUT	PIND
#define ADF_PORT_DIR_MUXOUT	DDRD
#define ADF_MUXOUT 		1

#define ADF_PORT_CE		PORTD
#define ADF_PORT_IN_CE		PIND
#define ADF_PORT_DIR_CE		DDRD
#define ADF_CE 			5
#endif

typedef union
{
	unsigned long whole_reg;
	struct {
		unsigned int lower;
		unsigned int upper;
	} word;
	unsigned char byte[4];
} adf_reg_t;

typedef struct {
	struct {
		double data_rate;
		double mod_index;
		unsigned long freq;
	} desired;
	struct {
		double data_rate;
		double mod_index;
		unsigned long freq;
		unsigned int freq_dev;
	} real;
	union {
		adf_reg_t r0_reg;
		struct {
			unsigned char address_bits : 4;
			unsigned int  frac_n : 15;
			unsigned int  int_n : 8;
			unsigned char rx_on : 1;
			unsigned char uart_mode : 1;
			unsigned char muxout : 3;
		} r0;
	};
	union {
		adf_reg_t r2_reg;
		struct {
			unsigned char address_bits : 4;
			unsigned char modulation_scheme : 3;
			unsigned char pa_enable : 1;
			unsigned char pa_ramp : 3;
			unsigned char pa_bias : 2;
			unsigned char power_amplifier : 6;
			unsigned int  tx_frequency_deviation : 9;
			unsigned char tx_data_invert : 2;
			unsigned char rcosine_alpha : 1;
		} r2;
	};
	union {
		adf_reg_t r3_reg;
		struct {
			unsigned char address_bits : 4;
			unsigned char bbos_clk_divide: 2;
			unsigned char dem_clk_divide : 4;
			unsigned char cdr_clk_divide : 8;
			unsigned char seq_clk_divide : 8;
			unsigned char agc_clk_divide : 6;
		} r3;
	};
	union {
		adf_reg_t r4_reg;
		struct {
			unsigned char address_bits : 4;
			unsigned char demod_scheme : 3;
			unsigned char dot_product : 1;
			unsigned char rx_invert : 2;
			unsigned int  disc_bw : 10;
			unsigned int  post_demod_bw : 10;
			unsigned char if_bw : 2;
		} r4;
	};
	union {
		adf_reg_t r5_reg;
		struct {
			unsigned char address_bits : 4;
			unsigned char if_cal_coarse : 1;
			unsigned int  if_filter_divider : 9;
			unsigned char if_filter_adjust : 6;
			unsigned char ir_phase_adjust_mag : 4;
			unsigned char ir_phase_adjust_direction : 1;
			unsigned char ir_gain_adjust_mac : 5;
			unsigned char ir_gain_adjust_iq : 1;
			unsigned char ir_gain_adjust_updn : 1;
		} r5;
	};
	union {
		adf_reg_t r6_reg;
		struct {
			unsigned char address_bits : 4;
			unsigned char if_fine_cal : 1;
			unsigned char if_cal_lower_tone : 8;
			unsigned char if_cal_upper_tone : 8;
			unsigned char if_cal_dwell_time : 7;
			unsigned char ir_cal_source_drive : 2;
			unsigned char ir_cal_source_div_2 : 1;
		} r6;
	};
} adf_conf_t;

typedef struct {
	unsigned long adf_xtal;
	union {
		adf_reg_t r1_reg;
		struct {
			unsigned char address_bits : 4;
			unsigned char r_counter : 3;
			unsigned char clockout_divide : 4;
			unsigned char xtal_doubler : 1;
			unsigned char xosc_enable : 1;
			unsigned char xtal_bias : 2;
			unsigned char cp_current : 2;
			unsigned char vco_enable : 1;
			unsigned char rf_divide_by_2 : 1;
			unsigned char vco_bias : 4;
			unsigned char vco_adjust : 2;
			unsigned char vco_inductor : 1;
		} r1;
	};
	union {
		adf_reg_t r10_reg;
		struct {
			unsigned char address_bits : 4;
			unsigned char afc_en : 1;
			unsigned int  afc_scaling_factor : 12;
			unsigned char ki : 4;
			unsigned char kp : 3;
			unsigned char afc_range : 8;
		} r10;
	};
	union {
		adf_reg_t r12_reg;
		struct {
			unsigned char address_bits : 4;
			unsigned char lock_thres_mode : 2;
			unsigned char swd_mode : 2;
			unsigned char packet_length : 8;
		} r12;
	};
	union {
		adf_reg_t r14_reg;
		struct {
			unsigned char address_bits : 4;
			unsigned char test_tdac_en : 1;
			unsigned int test_dac_offset : 16;
			unsigned char test_dac_gain : 4;
			unsigned char pulse_ext : 2;
			unsigned char leak_factor : 3;
			unsigned char ed_peak_resp : 2;
		} r14;
	};
	union {
		adf_reg_t r15_reg;
		struct {
			unsigned char address_bits : 4;
			unsigned char rx_test_mode : 4;
			unsigned char tx_test_mode : 3;
			unsigned char sd_test_mode : 3;
			unsigned char cp_test_mode : 3;
			unsigned char clk_mux : 3;
			unsigned char pll_test_mode : 4;
			unsigned char analog_test_mode : 4;
			unsigned char force_ld_high : 1;
			unsigned char reg1_pd : 1;
			unsigned char cal_override : 2;
		} r15;
	};
} adf_sysconf_t;

void adf_write_reg(adf_reg_t *reg);
adf_reg_t adf_read_reg(unsigned int readback_config);

void adf_set_power_on(unsigned long adf_xtal);
void adf_set_power_off(void);

void adf_init_rx_mode(unsigned int data_rate, uint8_t mod_index, unsigned long freq, uint8_t if_bw);
void adf_init_tx_mode(unsigned int data_rate, uint8_t mod_index, unsigned long freq);
void adf_set_rx_mode(void);
void adf_set_tx_mode(void);

void adf_afc_on(unsigned char range, unsigned char ki, unsigned char kp);
void adf_afc_off(void);
void adf_set_tx_power(char pasetting);

#define ADF_SYNC_WORD_LEN_12	        0
#define ADF_SYNC_WORD_LEN_16	        1
#define ADF_SYNC_WORD_LEN_20	        2
#define ADF_SYNC_WORD_LEN_24	        3
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

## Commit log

2012-10-20 firmware: add interrupt endpoints
2012-10-24 firmware: switch back to teensy board
2012-10-24 firmware: clear IN endpoint when data is updated
    This seemingly solves the problem with messages being shifted.
    [bluebox.c]
2012-10-24 firmware: use bulk transfers instead of interrupt
2012-10-25 firmware: clean up and add LED control code
2012-10-29 firmware: use TIMER1 for flashing LED
2012-11-05 firmware: fix missing bracket in timer interrupt
    [bluebox.c]
2012-11-05 firmware: use interrupt transfers with 5ms polling interval
2012-11-05 firmware: fix return value in timer_init
    [bluebox.c]
2012-11-07 hardware: add preliminary schematics
    The schematics need to be updated with correct component values.
2012-11-07 firmware: add adf7021 driver
    still not working though...
    [adf7021.c, adf7021.h, bluebox.c]
2012-11-10 firmware: fix adf7021 driver ports
    [adf7021.c, adf7021.h, bluebox.c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]
2012-11-10 bbctl: remove LED and loopback code, add data commands
2012-11-10 firmware: fix register read
    [bluebox.c, bluebox.h, spi.c]
2012-11-14 firmware: clean up SPI headers a bit
2012-11-16 bbctl: fix printing of non-optional arguments
    I prefer <argument> when listing required arguments.
2012-11-17 firmware: fix transmit, receive and framing
    [bluebox.c, bluebox.h, spi.c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]
2012-11-17 firmware: swap LED pins, fix last byte tx error
    [led.h, spi.c]
2012-11-19 bbctl: do not try to detach kernel driver on Windows
    is_kernel_driver_active() is not supported on windows.
2012-11-19 bbctl: add power set/get function
2012-11-19 firmware: implement power config and ptt
2012-11-20 firmware: add missing ptt.h file
    [ptt.h]
2012-11-28 firmware: set sync word tolerance to 3 errors
    [bluebox.h]
2012-12-01 bbctl: print error if asked to encode/decode without key
2012-12-10 firmware: flash leds when rebooting
    [bluebox.c, bluebox.h]
2012-12-22 bluebox: update USB PID to match OpenMoko assigned number
    Thanks to OpenMoko for allocating us a PID.
    See this page for a list of PID allocations:
    http://wiki.openmoko.org/wiki/USB_Product_IDs
2013-01-07 bbctl: add proper USB PID to udev rules
2013-01-16 firmware: enable Wall/Wextra and fix sign comparison warning
    [spi.c]
2013-01-28 firmware: fix AFC scaling factor to match XTAL freq
    431 matches old 19.44 MHz crystal.
    [adf7021.c]
2013-02-04 firmware: lower sync word error tolerance to 1 bit error
    [bluebox.h]
2013-02-14 firmware: fix external PA/LNA PTT control
    [adf7021.c, bluebox.c, bluebox.h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]
2013-02-14 firmware: only power on TX LED when transmitting
2013-02-16 firmware: defer RF reconfiguration to idle periods
    Avoid reconf in the middle of an RX or TX frame
    [bluebox.c, bluebox.h, spi.c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]
2013-02-17 firmware: fix spi_busy() prototype
    [spi.h]
2013-02-17 firmware: mark packet progress fields as volatile
    The missing volatile modifier modifier resulted in transmissions without
    training sequence if compiled with gcc 4.5. Ouch.
    [bluebox.h]
2013-03-09 firmware: set SW error tolerance to 3 bit errors
    [bluebox.h]
2013-05-10 firmware: add support for bluebox micro
    Use BBBOARD=micro for make to compile for the new board
2013-05-18 hardware: added files for the bluebox micro 1a
    bluebox micro 1a is a usb stick format ground station. these files
    contains gerber, altium source files and a pdf of the schematic (CC
    BY-SA).
2016-03-29 HW: prelim work on new version. Small changes for cost improvement and LDO on LNA
    [bluebox-micro-1B.PcbDoc, bluebox-micro-1B.PcbLib, bluebox-micro-1B.PrjPCB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]
2016-03-30 HW: WIP increase track and anular ring and clearence.
    [bluebox-micro-1B.PcbDoc, bluebox-micro-1B.PcbLib, bluebox-micro-1B.PrjPCB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]
2016-04-02 HW: almost there.
    [bluebox-micro-1B.PcbDoc, bluebox-micro-1B.PcbLib, mcu.SchDoc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]
2016-04-07 HW: proto. pcb on the way.
    [bluebox-micro-1B.PcbDoc, bluebox-micro-1B.PrjPCB]
2016-04-16 firmware: do not blink LEDs on startup
